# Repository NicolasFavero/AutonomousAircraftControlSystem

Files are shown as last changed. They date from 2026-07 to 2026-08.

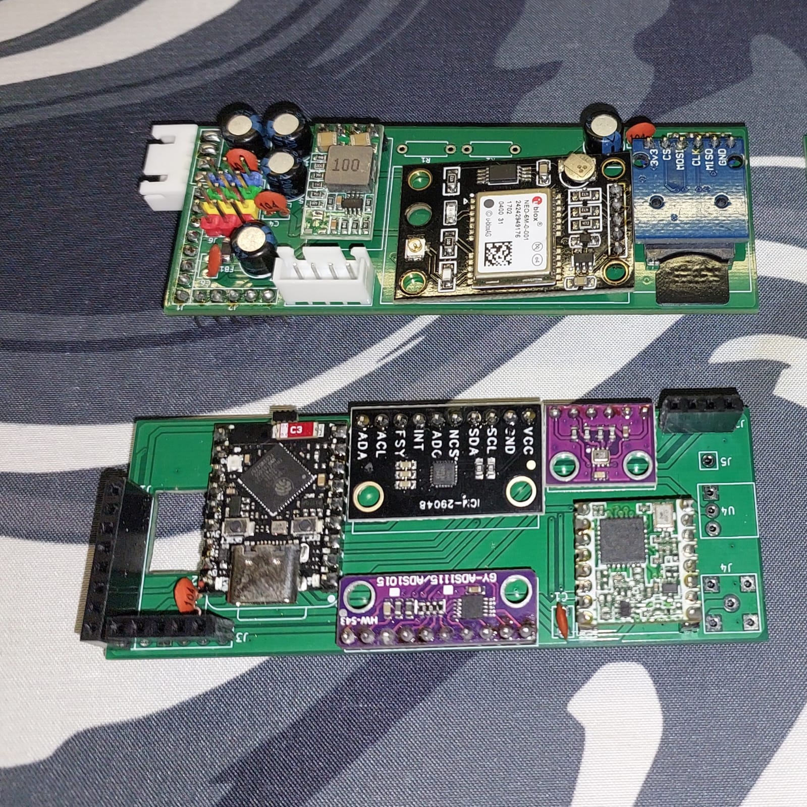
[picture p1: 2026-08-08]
media/pcb/image2.jpeg

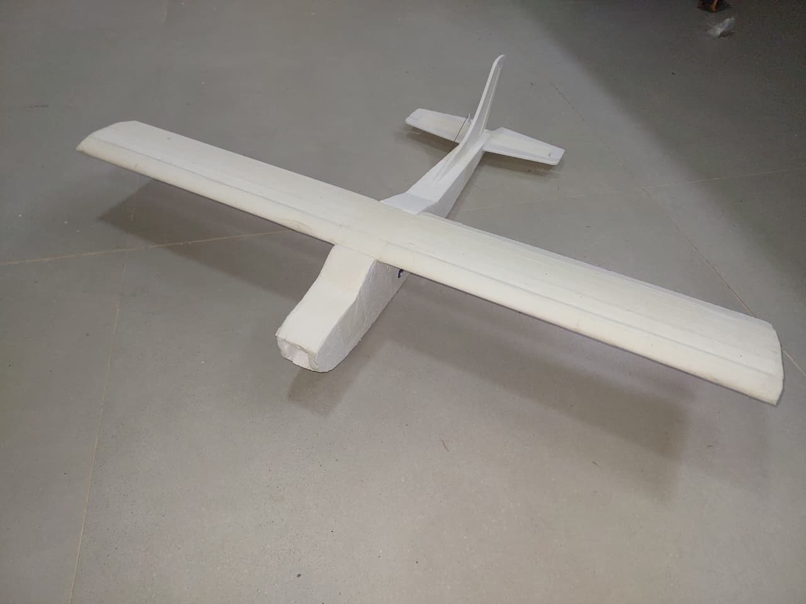
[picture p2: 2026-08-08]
media/aircraft/image3.jpeg

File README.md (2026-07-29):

# Sistema de Controle e Telemetria para Aeromodelo Autônomo

## Sobre o projeto

Este projeto consiste no desenvolvimento de um **sistema embarcado de controle, navegação e telemetria para uma asa autônoma / aeromodelo planador experimental**.

O sistema é baseado em um **ESP32-S3** e tem como finalidade realizar a aquisição de dados de voo, processamento de sensores, controle das superfícies móveis da aeronave e armazenamento das informações para análise posterior.

O projeto encontra-se em fase de **protótipo e desenvolvimento**, sendo utilizado para testes de hardware, sensores, algoritmos de controle e integração de sistemas embarcados.

---

## Objetivo

Desenvolver uma plataforma experimental para estudo e implementação de um sistema de controle autônomo para aeronaves de pequeno porte, integrando:

* Sensoriamento inercial e ambiental;
* Controle eletrônico das superfícies de comando;
* Registro de dados de voo;
* Desenvolvimento de firmware embarcado;
* Testes e validação de sistemas aplicados à aviação experimental.

---

## Funcionalidades

* Leitura de sensores inerciais:

  * Aceleração;
  * Velocidade angular;
  * Campo magnético;
* Medição de altitude e pressão atmosférica utilizando BMP280;
* Leitura de velocidade do ar através de tubo de Pitot;
* Controle das superfícies de comando:

  * Leme;
  * Aileron;
  * Profundor;
* Controle de servomotores;
* Registro de dados de voo em cartão SD;
* Estrutura preparada para futuras expansões, como telemetria e algoritmos de controle autônomo.

---

## Status do projeto

🚧 **Protótipo em desenvolvimento**

O firmware e o hardware ainda estão em fase experimental. Alterações na arquitetura, sensores utilizados e funcionalidades podem ocorrer durante o desenvolvimento.

---

## Tecnologias utilizadas

### Hardware

* ESP32-S3 SuperMini;
* ICM-20948 (IMU 9DOF);
* BMP280 (pressão e altitude);
* Tubo de Pitot;
* Servomotores;
* Cartão SD.

### Software

* C / C++;
* PlatformIO;
* Arduino Framework.

---

## Dependências

```ini
lib_deps =
	sparkfun/SparkFun 9DoF IMU Breakout - ICM 20948 - Arduino Library@^1.3.2
	adafruit/Adafruit ADS1X15@^2.6.2
	adafruit/Adafruit BMP280 Library@^3.0.0
	mikalhart/TinyGPSPlus@^1.1.0
	greiman/SdFat@^2.3.1
	jgromes/RadioLib@^7.7.1
```

---

## Ambiente de desenvolvimento

* IDE: PlatformIO;
* Framework: Arduino;
* Placa alvo: ESP32-S3 SuperMini.

---

## Estrutura do projeto

```
Firmware/
├── src/
├── include/
├── lib/
└── platformio.ini
```

---

## Aplicação

Projeto desenvolvido para fins educacionais e experimentais, integrando conhecimentos de **eletrônica, programação embarcada, sensores, controle e sistemas aeronáuticos** dentro de uma formação técnica em eletrônica.

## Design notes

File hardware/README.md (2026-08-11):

# Hardware

Esta pasta contém os arquivos de hardware do projeto, incluindo esquemáticos, layouts e demais arquivos relacionados às placas de circuito impresso (PCBs).

O sistema foi dividido em **duas PCBs empilháveis**, conectadas através de **headers macho e fêmea (2,54 mm)**. Essa arquitetura facilita a montagem, manutenção e futuras revisões do hardware, além de permitir uma melhor organização dos circuitos.

## PCB-Top

A **PCB-Top** concentra os circuitos de alimentação, armazenamento e navegação da aeronave, incluindo:

- Receptor GPS;
- Slot para cartão microSD;
- Conector da bateria;
- Conectores para servomotores;
- Conversor Buck (Step-Down);
- Capacitores de bulk para estabilização da alimentação;
- Distribuição das tensões de alimentação.

Também é nesta placa que ocorre a separação entre as linhas de alimentação de **3,3 V**, utilizando **ferrite beads** para isolar os diferentes domínios de alimentação, reduzindo a propagação de ruído entre os circuitos analógicos, digitais e de RF.

## PCB-Bottom

A **PCB-Bottom** concentra os circuitos responsáveis pelo processamento, sensoriamento e comunicação da aeronave, incluindo:

- ESP32-S3 SuperMini;
- IMU ICM-20948;
- BMP280;
- ADS1115;
- Módulo LoRa (RF96W ou módulos compatíveis da mesma família, como CC68);
- Conector para antena;
- Interface para tubo de Pitot.

A proximidade entre esses componentes reduz o comprimento das trilhas dos barramentos de comunicação e dos sinais de alta frequência, contribuindo para uma melhor integridade dos sinais.

## Interconexão

As duas placas são interligadas através de **headers macho e fêmea**, formando um conjunto compacto e removível.

Essa abordagem oferece diversas vantagens:

- Organização dos circuitos por função;
- Facilidade de montagem e manutenção;
- Possibilidade de substituir apenas uma das placas em futuras revisões;
- Redução da complexidade do roteamento;
- Melhor gerenciamento da distribuição de alimentação.

## Estrutura

```text
Hardware/
├── PCB-Top/
└── PCB-Bottom/
```

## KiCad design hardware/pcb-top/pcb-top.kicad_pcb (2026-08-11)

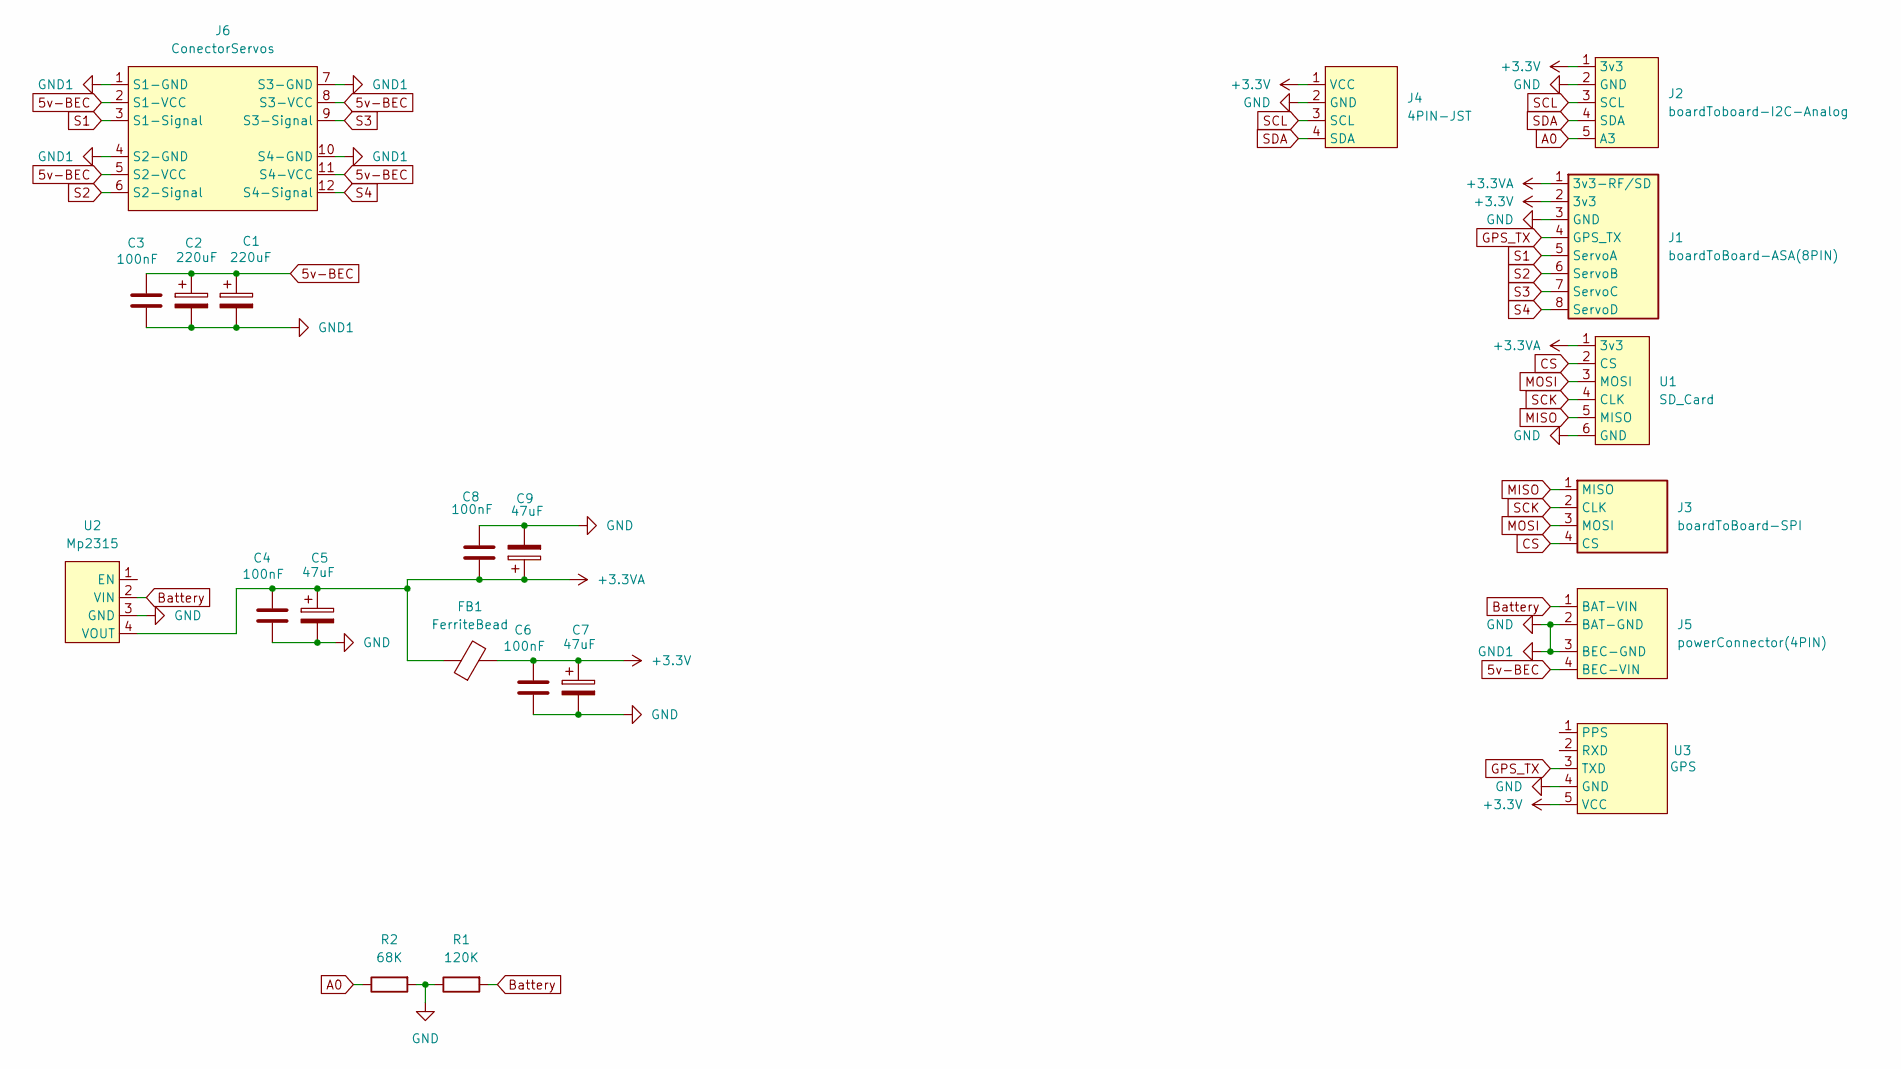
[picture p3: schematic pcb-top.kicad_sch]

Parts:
C1, C2: 220uF; CP_Radial_D6.3mm_P2.50mm
C3, C4, C6, C8: 100nF; C_Disc_D3.8mm_W2.6mm_P2.50mm
C5, C7, C9: 47uF; CP_Radial_D6.3mm_P2.50mm
FB1: FerriteBead; R_1206_3216Metric_Pad1.30x1.75mm_HandSolder
J1: boardToBoard-ASA(8PIN); PinSocket_1x08_P2.54mm_Vertical
J2: boardToboard-I2C-Analog; PinHeader_1x05_P2.54mm_Vertical
J3: boardToBoard-SPI; PinHeader_1x04_P2.54mm_Vertical
J4: 4PIN-JST; JST_XH_B4B-XH-A_1x04_P2.50mm_Vertical
J5: powerConnector(4PIN); ConnectorBaterry+BEC
J6: ConectorServos; 4Servos
R1: 120K; R_Axial_DIN0207_L6.3mm_D2.5mm_P7.62mm_Horizontal
R2: 68K; R_Axial_DIN0207_L6.3mm_D2.5mm_P7.62mm_Horizontal
U1: SD_Card
U2: Mp2315
U3: GPS

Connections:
5v-BEC: C1.1, C2.1, C3.1, J5.4 (BEC-VIN), J6.2 (S1-VCC), J6.5 (S2-VCC), J6.8 (S3-VCC), J6.11 (S4-VCC)
+3.3V: C6.1, C7.1, FB1.2, J1.2 (3v3), J2.1 (3v3), J4.1 (VCC), U3.5 (VCC)
+3.3VA: C4.1, C5.1, C8.1, C9.1, FB1.1, J1.1 (3v3-RF/SD), U1.1 (3v3), U2.4 (VOUT)
A0: J2.5 (A3), R2.1
Battery: J5.1 (BAT-VIN), R1.2, U2.2 (VIN)
CS: J3.4 (CS), U1.2 (CS)
GND: C1.2, C2.2, C3.2, C4.2, C5.2, C6.2, C7.2, C8.2, C9.2, J1.3 (GND), J2.2 (GND), J4.2 (GND), J5.2 (BAT-GND), J5.3 (BEC-GND), J6.1 (S1-GND), J6.4 (S2-GND), J6.7 (S3-GND), J6.10 (S4-GND), R1.1, R2.2, U1.6 (GND), U2.3 (GND), U3.4 (GND)
GPS_TX: J1.4 (GPS_TX), U3.3 (TXD)
MISO: J3.1 (MISO), U1.5 (MISO)
MOSI: J3.3 (MOSI), U1.3 (MOSI)
S1: J1.5 (ServoA), J6.3 (S1-Signal)
S2: J1.6 (ServoB), J6.6 (S2-Signal)
S3: J1.7 (ServoC), J6.9 (S3-Signal)
S4: J1.8 (ServoD), J6.12 (S4-Signal)
SCK: J3.2 (CLK), U1.4 (CLK)
SCL: J2.3 (SCL), J4.3 (SCL)
SDA: J2.4 (SDA), J4.4 (SDA)

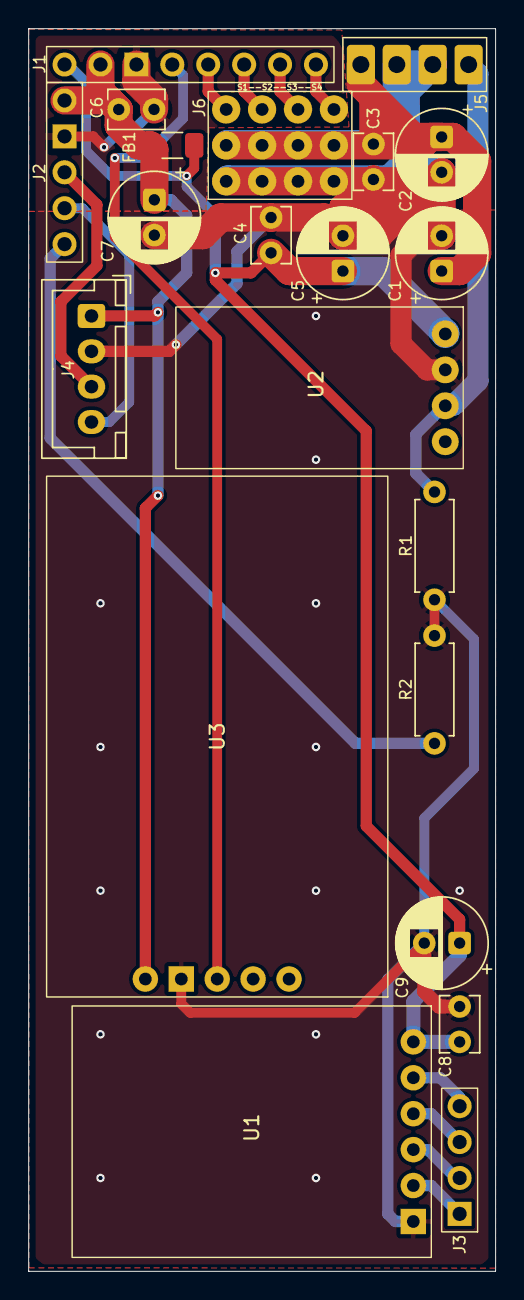
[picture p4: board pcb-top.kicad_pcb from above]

Board: 2 copper layers, 33.0 x 87.9 mm, 21 parts (0 on the bottom side), 17 nets.

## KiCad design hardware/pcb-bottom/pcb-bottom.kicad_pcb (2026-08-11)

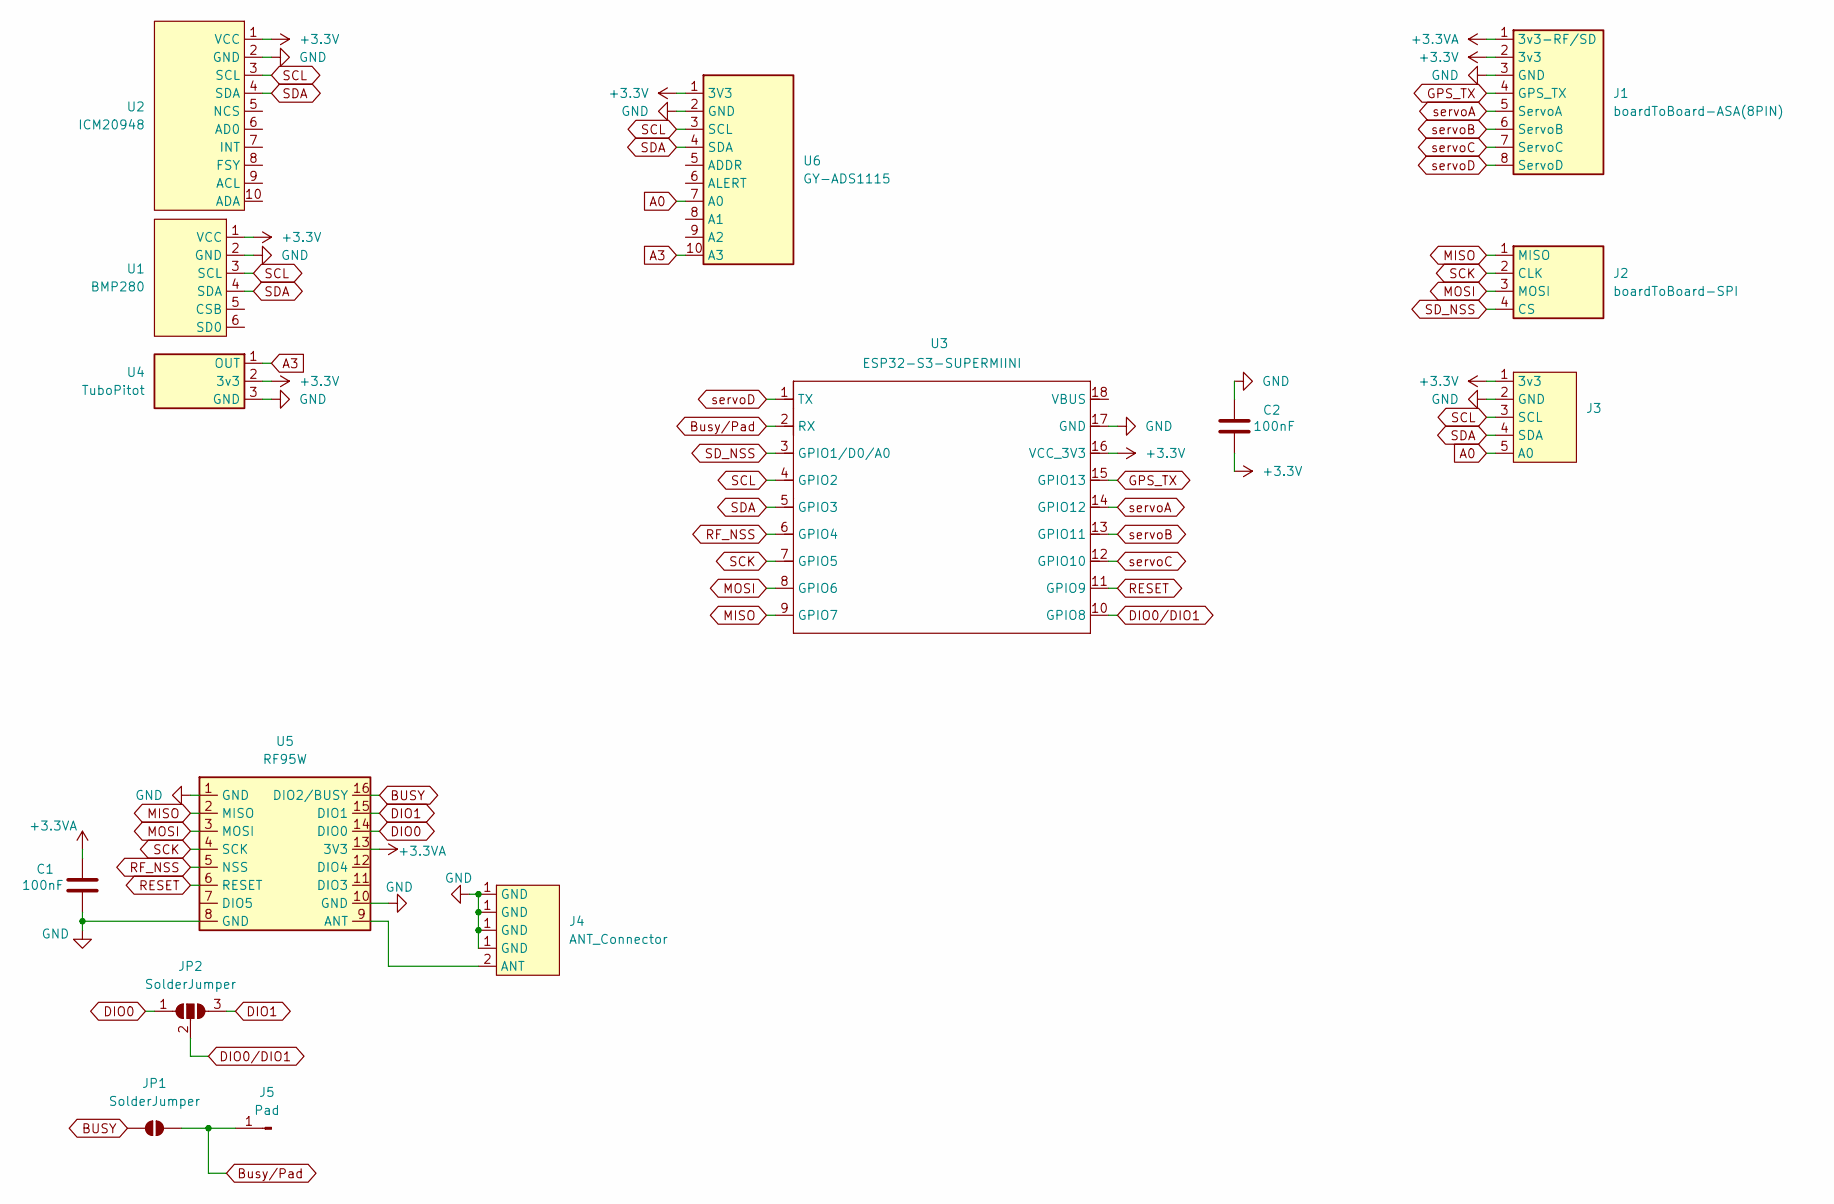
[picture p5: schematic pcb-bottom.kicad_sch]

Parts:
C1, C2: 100nF; C_Disc_D3.8mm_W2.6mm_P2.50mm
J1: boardToBoard-ASA(8PIN); PinHeader_1x08_P2.54mm_Vertical
J2: boardToBoard-SPI; PinHeader_1x04_P2.54mm_Vertical
J3: PinHeader_1x05_P2.54mm_Vertical
J4: ANT_Connector; conectorAntena2.54mm
J5: Pad; PinHeader_1x01_P2.54mm_Vertical
JP1: SolderJumper; SolderJumper-2_P1.3mm_Open_RoundedPad1.0x1.5mm
JP2: SolderJumper; SolderJumper-3_P1.3mm_Open_RoundedPad1.0x1.5mm
U1: BMP280
U2: ICM20948; ICM 20948
U3: ESP32-S3-SUPERMIINI; myEsp32-S3-Mini
U4: TuboPitot; tuboPitot
U5: RF95W; rf96w
U6: GY-ADS1115; ads1115

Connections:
+3.3V: C2.1, J1.2 (3v3), J3.1 (3v3), U1.1 (VCC), U2.1 (VCC), U3.16 (VCC_3V3), U4.2 (3v3), U6.1 (3V3)
+3.3VA: C1.2, J1.1 (3v3-RF/SD), U5.13 (3V3)
A0: J3.5 (A0), U6.7 (A0)
A3: U4.1 (OUT), U6.10 (A3)
BUSY: JP1.1 (A), U5.16 (DIO2/BUSY)
Busy/Pad: J5.1, JP1.2 (B), U3.2 (RX)
DIO0: JP2.1 (A), U5.14 (DIO0)
DIO0/DIO1: JP2.2 (C), U3.10 (GPIO8)
DIO1: JP2.3 (B), U5.15 (DIO1)
GND: C1.1, C2.2, J1.3 (GND), J3.2 (GND), J4.1 (GND), U1.2 (GND), U2.2 (GND), U3.17 (GND), U4.3 (GND), U5.1 (GND), U5.8 (GND), U5.10 (GND), U6.2 (GND)
GPS_TX: J1.4 (GPS_TX), U3.15 (GPIO13)
MISO: J2.1 (MISO), U3.9 (GPIO7), U5.2 (MISO)
MOSI: J2.3 (MOSI), U3.8 (GPIO6), U5.3 (MOSI)
unnamed: J4.2 (ANT), U5.9 (ANT)
RESET: U3.11 (GPIO9), U5.6 (RESET)
RF_NSS: U3.6 (GPIO4), U5.5 (NSS)
SCK: J2.2 (CLK), U3.7 (GPIO5), U5.4 (SCK)
SCL: J3.3 (SCL), U1.3 (SCL), U2.3 (SCL), U3.4 (GPIO2), U6.3 (SCL)
SDA: J3.4 (SDA), U1.4 (SDA), U2.4 (SDA), U3.5 (GPIO3), U6.4 (SDA)
SD_NSS: J2.4 (CS), U3.3 (GPIO1/D0/A0)
servoA: J1.5 (ServoA), U3.14 (GPIO12)
servoB: J1.6 (ServoB), U3.13 (GPIO11)
servoC: J1.7 (ServoC), U3.12 (GPIO10)
servoD: J1.8 (ServoD), U3.1 (TX)

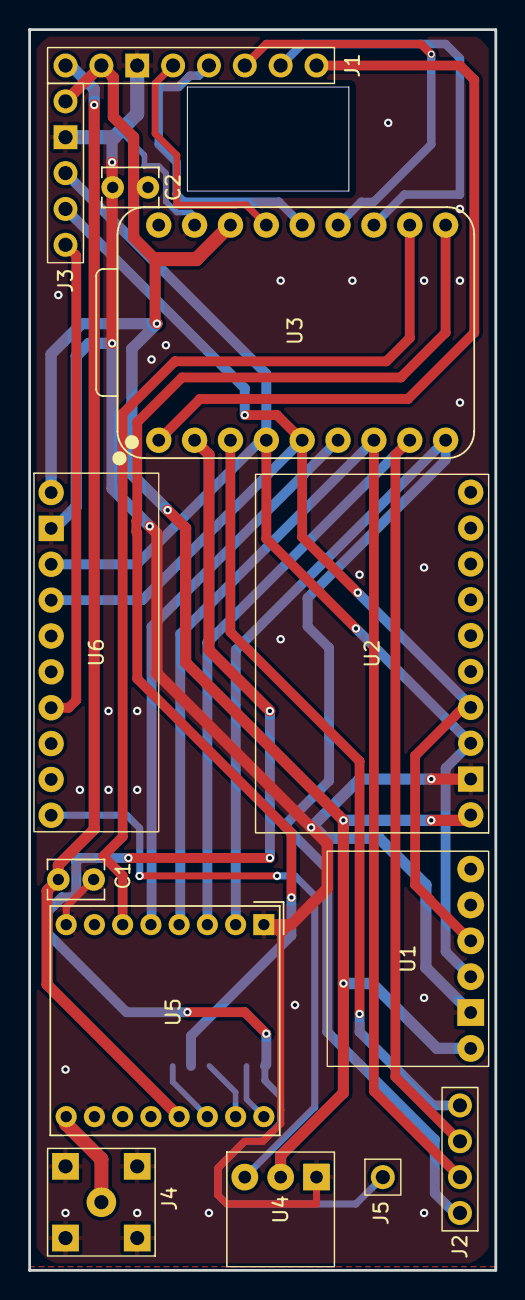
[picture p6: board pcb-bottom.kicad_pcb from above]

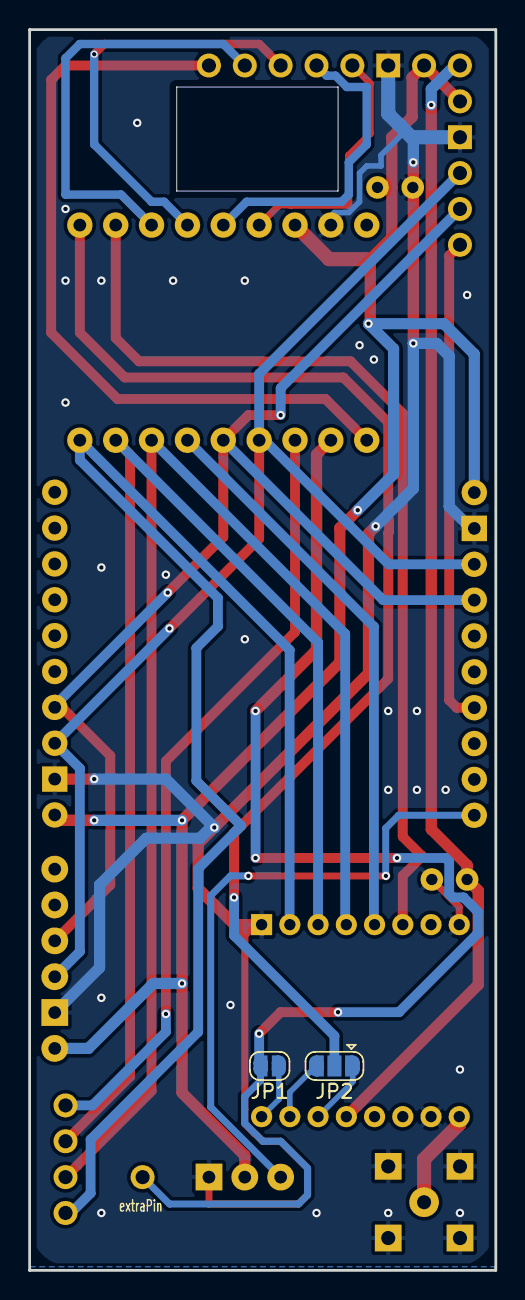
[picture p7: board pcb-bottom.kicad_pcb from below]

Board: 2 copper layers, 33.0 x 87.9 mm, 15 parts (2 on the bottom side), 24 nets.

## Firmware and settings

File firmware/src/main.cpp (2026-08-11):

// Arduino
#include "Arduino.h"

// Config
#include "Pins.h"
#include "ServomotorConfig.h"
#include "DataTypes.h"
#include "CurrentConfig.h"

// Drivers
#include "IMU.h"
#include "GPS.h"
#include "ApplyGpsConfig.h"
#include "gpsSettings.h"
#include "BMP280.h"
#include "ADS1X15.h"
#include "Pitot.h"

// Communication
#include "RF96W.h"
#include "WiFiAP.h"

// Storage
#include "SdLogger.h"
#include "PreferencesManager.h"

// Control
#include "PID.h"
#include "Servo.h"

// Telemetry
#include "Telemetry.h" //ALTEREI PRA DEBUG     float pitch = imuValid ? attitude.pitch : 0.0f; LEMBRAR DE VOLTAR ATRAS DEPOIS!!!!!!!!!!!!!!!

// Debug
#include "Led.h"
//=======================================================================================================================================================
//OTHERS
unsigned long lastTelemetryMillis = 0;
unsigned long countdownStartMillis = 0;
constexpr unsigned long COUNTDOWN_DURATION_MS = 10000; // mesmo valor do COUNTDOWN_DURATION_S no script.js

// Timer PROPRIO do registro no SD (ver handleOutputs()) -- antes
// reusava a mesma lastTelemetryMillis do envio LoRa, o que fazia o
// registro no SD "resetar o relogio" que o LoRa checava logo em
// seguida, e o LoRa quase nunca dava tempo de vencer o periodo
// configurado. Agora sao independentes: SD grava a cada
// SD_LOG_INTERVAL_MS, LoRa manda a cada systemConfig.telemetryPeriodMs,
// sem um atrapalhar o outro.
unsigned long lastSdMillis = 0;
constexpr unsigned long SD_LOG_INTERVAL_MS = 10;
volatile bool newOffsetsAvailable = false;
volatile bool newPidAvailable = false;

bool wifiEnabled = false;
bool wifiTemporary = false;

unsigned long wifiStartMillis = 0;
//==================================================================STRUCTS===============================================================================
ImuOffsets currentOffsets;
PidConfig currentPidConfig;
SystemConfig systemConfig;
SystemStatus systemStatus;
GpsConfigStatus gpsConfigStatus;
//========================================================================================================================================================
//==================================================================CLASSES==============================================================================
// Drivers
IMU imu;
ADS ads;
Pitot pitot(ads);
BMP280 bmp;

// GPS: ApplyGpsConfig (aplicada uma vez em beginGps(), setup()) e GPS
// (parser continuo, TinyGPSPlus) compartilham a MESMA UART -- nenhuma
// das duas possui/cria a HardwareSerial, so' recebem por referencia.
HardwareSerial gpsSerial(1);
GPS gps(gpsSerial);

// Communication
RF96W lora(Pins::LORA_CS, Pins::LORA_DIO0, Pins::LORA_RESET, systemConfig.lora);
WifiAP wifi;

// Storage
SdLogger sd(Pins::SD_CS);
PreferencesManager nvs;

// Control
PID pid;

// Actuators
//
// minAngle/maxAngle (ultimos 2 args) NAO sao mais o default generico
// 0-180 do construtor -- sao o fim de curso mecanico real de cada servo
// (ServoConfig::SafeRange), pra' write() (lib/Servo) recusar qualquer
// angulo fora disso, venha de onde vier a chamada (PID ou o trim
// direto em main.cpp). Antes disso um trim grande demais no "Aplicar e
// Travar Servos" conseguia mandar o servo direto pro batente fisico
// sem nenhum clamp no meio do caminho.
Servo elevator    (Pins::ELEVATOR,      ServoConfig::Channel::ELEVATOR,      ServoConfig::FREQUENCY, ServoConfig::RESOLUTION, 500, 2500, ServoConfig::SafeRange::ELEVATOR_MIN,      ServoConfig::SafeRange::ELEVATOR_MAX);
Servo leftAlieron (Pins::LEFT_AILERON,  ServoConfig::Channel::LEFT_AILERON,  ServoConfig::FREQUENCY, ServoConfig::RESOLUTION, 500, 2500, ServoConfig::SafeRange::LEFT_AILERON_MIN,  ServoConfig::SafeRange::LEFT_AILERON_MAX);
Servo rightAlieron(Pins::RIGHT_AILERON, ServoConfig::Channel::RIGHT_AILERON, ServoConfig::FREQUENCY, ServoConfig::RESOLUTION, 500, 2500, ServoConfig::SafeRange::RIGHT_AILERON_MIN, ServoConfig::SafeRange::RIGHT_AILERON_MAX);
//Servo rudder    (Pins::RUDDER,        ServoConfig::Channel::RUDDER,        ServoConfig::FREQUENCY, ServoConfig::RESOLUTION); 

// Telemetry
Telemetry telemetry;

//Visual Debug
Led led;

//========================================================================================================================================================
//==============================================================FREEERTOS QUEUES===============================================================================
QueueHandle_t attitudeQueue;
QueueHandle_t navigationQueue;
portMUX_TYPE offsetMux = portMUX_INITIALIZER_UNLOCKED;
portMUX_TYPE pidMux = portMUX_INITIALIZER_UNLOCKED;
//========================================================================================================================================================
//=================================================================PROTOTYPES=============================================================================
// TASKS
void taskControl(void *pv);
void taskData(void *pv);

// TASK CONTROL HELPERS
bool readAttitudeData(AttitudeData& attitude);
void syncPidNeutralAngles();

// TASK DATA HELPERS
void sendNavigationData(NavigationData& navigationData);
void handleWifiTimeout();
void handleOutputs(FlightMode mode);
void handleWifi(const AttitudeData& attitude, const NavigationData& navigationData);
void updateGpsStatus();
void setupWifi();
bool beginGps();
TelemetryData buildTelemetryData(AttitudeData& attitude);
// GENERAL HELPERS
bool isLowPowerModeEnabled();

// Recalcula o neutro (BaseNeutral + trim) dos 3 servos a partir de
// currentPidConfig -- inclui o sinal do trim invertido quando
// invertFlaperonTrim/invertElevatorTrim esta' ligado (ver comentario
// em PidConfig, DataTypes.h: existe pq o teclado numerico do celular
// nao tem "-"). Chamada tanto no boot quanto sempre que a config muda
// (bloco "newPidAvailable" em taskControl()), pra nao duplicar essa
// conta nos dois lugares.
void syncPidNeutralAngles(){
  float flapTrim = currentPidConfig.invertFlaperonTrim
      ? -currentPidConfig.flaperonTrim
      : currentPidConfig.flaperonTrim;

  float elevTrim = currentPidConfig.invertElevatorTrim
      ? -currentPidConfig.elevatorTrim
      : currentPidConfig.elevatorTrim;

  // Clampado no fim de curso real (ServoConfig::SafeRange) -- sem isso
  // um trim grande demais produzia um neutralAngle fora do range
  // seguro, e o "Aplicar e Travar Servos" (setAngle = neutralAngle,
  // logo abaixo) escrevia esse valor DIRETO no servo sem passar por
  // nenhum constrain (diferente do caminho do PID, que sempre clampou
  // via PID::applyServoOutput). O objeto Servo (lib/Servo) tambem
  // clampa no mesmo range como ultima linha de defesa, mas isso aqui
  // evita que a UI mostre um "neutro" mentiroso, fora do que o servo
  // fisicamente consegue atingir.
  pid.elevator.neutralAngle = constrain(
      ServoConfig::BaseNeutral::ELEVATOR + elevTrim,
      ServoConfig::SafeRange::ELEVATOR_MIN,
      ServoConfig::SafeRange::ELEVATOR_MAX
  );

  pid.leftAileron.neutralAngle = constrain(
      ServoConfig::BaseNeutral::LEFT_AILERON + flapTrim,
      ServoConfig::SafeRange::LEFT_AILERON_MIN,
      ServoConfig::SafeRange::LEFT_AILERON_MAX
  );

  pid.rightAileron.neutralAngle = constrain(
      ServoConfig::BaseNeutral::RIGHT_AILERON - flapTrim,
      ServoConfig::SafeRange::RIGHT_AILERON_MIN,
      ServoConfig::SafeRange::RIGHT_AILERON_MAX
  );
}

//=========================================================================================================================================================
//===================================================================SETUP=================================================================================
void setup(){
  Serial.begin(115200);
  Serial.println("Beginning...");
  Wire.begin(Pins::SDA, Pins::SCL);
  Wire.setClock(400000); 

  SPI.begin(Pins::SCK, Pins::MISO, Pins::MOSI);

  led.white();
  //led.white();

  nvs.loadSystem(systemConfig);
  nvs.loadOffsets(currentOffsets);
  nvs.loadPid(currentPidConfig);

  pitot.setZeroVoltage(currentOffsets.pitotZeroVoltage);

  // Sem isso, o offset salvo nas Preferences so era realmente
  // aplicado no calculo do angulo (localOffsets, dentro da task de
  // controle) depois que o usuario salvasse um offset pela web --
  // ate la, localOffsets ficava zerado mesmo com currentOffsets/
  // /api/status ja reportando o valor salvo do boot anterior. Isso
  // fazia a primeira tara depois de ligar somar o offset antigo (que
  // NAO estava de fato sendo subtraido da leitura) com o novo valor
  // calculado, dando um offset errado logo na primeira vez -- so
  // acertava no segundo, quando o evento OFFSET_CHANGED sincronizava
  // localOffsets pela primeira vez. Marcando newOffsetsAvailable aqui,
  // a task de controle sincroniza localOffsets = currentOffsets logo
  // na primeira iteracao do loop, antes de qualquer leitura ser usada.
  newOffsetsAvailable = true;

  pid.pitch.kp = currentPidConfig.pitch.kp;
  pid.pitch.ki = currentPidConfig.pitch.ki;
  pid.pitch.kd = currentPidConfig.pitch.kd;
  pid.pitch.integralLimit = currentPidConfig.pitch.integralLimit;

  pid.roll.kp = currentPidConfig.roll.kp;
  pid.roll.ki = currentPidConfig.roll.ki;
  pid.roll.kd = currentPidConfig.roll.kd;
  pid.roll.integralLimit = currentPidConfig.roll.integralLimit;

  pid.yaw.kp = currentPidConfig.yaw.kp;
  pid.yaw.ki = currentPidConfig.yaw.ki;
  pid.yaw.kd = currentPidConfig.yaw.kd;
  pid.yaw.integralLimit = currentPidConfig.yaw.integralLimit;

  // Neutro fisico (ServoConfig::BaseNeutral) + trim configuravel
  // (currentPidConfig, carregado das Preferences acima) -- sem isso,
  // leftAileron/rightAileron ficariam nos 90.0f default de
  // PID::ServoParamters (errado: a base fisica real e' 85/103) ate a
  // primeira mudanca de PID pela pagina web. setAngle tambem e' fixado
  // aqui pro servo ja nascer na posicao certa (fora do modo FLIGHT,
  // computePID() nao roda pra atualizar isso sozinho).
  syncPidNeutralAngles();

  pid.elevator.setAngle    = pid.elevator.neutralAngle;
  pid.leftAileron.setAngle = pid.leftAileron.neutralAngle;
  pid.rightAileron.setAngle = pid.rightAileron.neutralAngle;

  while(!imu.begin()){led.red();}
  Serial.println("[BOOT] IMU ok");

  while(!bmp.begin()){led.red();}
  Serial.println("[BOOT] BMP280 ok");

  Serial.println("[BOOT] Iniciando GPS (beginGps())...");
  gpsSerial.begin(9600, SERIAL_8N1, Pins::GPS_TX, Pins::GPS_RX);
  delay(10);
  while(!beginGps()){led.red();}
  Serial.println("[BOOT] GPS ok");

  // TESTE SEM ADS1115: pulando ads.begin() (sem isso, o while
  // travaria pra sempre esperando um chip que nao esta na placa).
  // while(!ads.begin()){led.red();}
  // Serial.println("[BOOT] ADS1115 ok");

  while(!lora.begin()){led.red();}
  Serial.println("[BOOT] LoRa ok");

  while(!elevator.begin()){led.red();}
  Serial.println("[BOOT] Servo elevator ok");

  while(!leftAlieron.begin()){led.red();}
  Serial.println("[BOOT] Servo aileron esquerdo ok");

  while(!rightAlieron.begin()){led.red();}
  Serial.println("[BOOT] Servo aileron direito ok");

  while(!sd.begin()) {Serial.println("SD FAIL"); led.red();}
  Serial.println("[BOOT] SD ok");

  // Buffer em RAM/PSRAM pros logs de voo -- ver comentarios em
  // SdLogger::beginBuffer()/bufferLine(). Se falhar (placa sem PSRAM
  // ou sem RAM livre suficiente), o firmware continua funcionando,
  // so volta a escrever direto no SD a cada leitura como antes.
  //
  // 512KB (era o default de 64KB) -- o log no SD agora grava a cada
  // SD_LOG_INTERVAL_MS (10ms, 10x mais rapido que antes), entao o
  // buffer tambem precisa ser maior pra continuar enchendo (e forcando
  // o flush real, bloqueante, no cartao) com a mesma frequencia de
  // antes em vez de 10x mais frequente. Cabe tranquilo na PSRAM do
  // ESP32-S3.
  sd.beginBuffer(512 * 1024);

  attitudeQueue = xQueueCreate(1, sizeof(AttitudeData));
  navigationQueue = xQueueCreate(1, sizeof(NavigationData));

  if(attitudeQueue == NULL || navigationQueue == NULL){
    while(true){
      led.red();
      delay(500);
    }
  }
  setupWifi();

  lastTelemetryMillis = millis();

  led.green();
  
  xTaskCreatePinnedToCore(
    taskControl,
    "Control",
    10000,
    NULL,
    2,
    NULL,
    0
  );
  xTaskCreatePinnedToCore(
    taskData,
    "Data",
    10000,
    NULL,
    1,
    NULL,
    1
  );
}
//==========================================================================================================================================================
//================================================================KILLING TASK==============================================================================
void loop(){vTaskDelete(NULL);}
//==========================================================================================================================================================
//=================================================================TASK AT CORE 0===========================================================================
void taskControl(void *pv){

  TickType_t lastWake = xTaskGetTickCount();
  const TickType_t period = pdMS_TO_TICKS(5); //200HZ

  while(true){
    bool useNewValues = true;

    static AttitudeData attitudeData;
    static NavigationData nav; 
    static ImuOffsets localOffsets; 
  //===================TO  ATTITUDE==============
    if(systemConfig.flightMode == FlightMode::CONFIG && newOffsetsAvailable){
      portENTER_CRITICAL(&offsetMux);

      localOffsets = currentOffsets;

      newOffsetsAvailable = false;

      portEXIT_CRITICAL(&offsetMux);
    }

    // Fora do CONFIG, so' processa mudanca de PID/trim se liveTuningEnabled
    // estiver ligado (marcado na hora de "Iniciar Voo", ver
    // handleStartFlight() em WifiAP.cpp) E o modo for FLIGHT de verdade
    // -- nunca em COUNTDOWN/LANDED, que continuam travados como sempre
    // (handlePid() ja rejeita o POST nesses casos antes de chegar aqui).
    bool pidLiveTuningNow =
        systemConfig.liveTuningEnabled &&
        systemConfig.flightMode == FlightMode::FLIGHT;

    if(newPidAvailable && (systemConfig.flightMode == FlightMode::CONFIG || pidLiveTuningNow)){
      portENTER_CRITICAL(&pidMux);

      pid.pitch.kp = currentPidConfig.pitch.kp;
      pid.pitch.ki = currentPidConfig.pitch.ki;
      pid.pitch.kd = currentPidConfig.pitch.kd;
      pid.pitch.integralLimit = currentPidConfig.pitch.integralLimit;

      pid.roll.kp = currentPidConfig.roll.kp;
      pid.roll.ki = currentPidConfig.roll.ki;
      pid.roll.kd = currentPidConfig.roll.kd;
      pid.roll.integralLimit = currentPidConfig.roll.integralLimit;

      pid.yaw.kp = currentPidConfig.yaw.kp;
      pid.yaw.ki = currentPidConfig.yaw.ki;
      pid.yaw.kd = currentPidConfig.yaw.kd;
      pid.yaw.integralLimit = currentPidConfig.yaw.integralLimit;

      syncPidNeutralAngles();

      // So' forca a posicao final (setAngle = neutralAngle) em CONFIG --
      // e' o que faz o servo se mover na hora que o trim muda, "forcar e
      // travar" na pagina Servos/PID (fora do FLIGHT, computePID() nao
      // roda pra atualizar isso sozinho). Durante o FLIGHT (so' chega
      // aqui com pidLiveTuningNow), computePID() ja' roda todo ciclo e
      // aplica o neutro/ganho novo sozinho -- forcar setAngle aqui
      // tambem brigaria com a correcao em tempo real dele.
      if(systemConfig.flightMode == FlightMode::CONFIG){
        pid.elevator.setAngle     = pid.elevator.neutralAngle;
        pid.leftAileron.setAngle  = pid.leftAileron.neutralAngle;
        pid.rightAileron.setAngle = pid.rightAileron.neutralAngle;
      }

      newPidAvailable = false;

      portEXIT_CRITICAL(&pidMux);
    }

    imu.update();

    if(systemConfig.flightMode == FlightMode::FLIGHT){
      pid.setAngles(attitudeData, nav, useNewValues);
    }


    elevator.write(pid.elevator.setAngle);
    leftAlieron.write(pid.leftAileron.setAngle);
    rightAlieron.write(pid.rightAileron.setAngle);

  //===================TO  ATTITUDE==============
  //=====================FOR SEND================
    attitudeData.pitch = imu.getPitch() - localOffsets.pitch;
    attitudeData.roll = imu.getRoll() - localOffsets.roll;
    attitudeData.yaw = imu.getYaw() - localOffsets.yaw;

    // Mesmo valor que acabou de ir pro elevator.write()/leftAlieron.write()/
    // rightAlieron.write() acima -- registrado aqui, e nao lido de volta do
    // servo, porque servo (PWM) nao tem telemetria de posicao real.
    attitudeData.servoElevator = pid.elevator.setAngle;
    attitudeData.servoLeftAileron = pid.leftAileron.setAngle;
    attitudeData.servoRightAileron = pid.rightAileron.setAngle;

    attitudeData.accX = imu.getAccX();
    attitudeData.accY = imu.getAccY();
    attitudeData.accZ = imu.getAccZ();

    attitudeData.gyroX = imu.getGyroX();
    attitudeData.gyroY = imu.getGyroY();
    attitudeData.gyroZ = imu.getGyroZ();

    attitudeData.magX= imu.getMagX();
    attitudeData.magY = imu.getMagY();
    attitudeData.magZ = imu.getMagZ();

    attitudeData.isImuOk = imu.isHealthy();

    xQueueOverwrite(attitudeQueue, &attitudeData);
  //=====================FOR SEND================
  //====================TO  RECEIVE==============
    if(xQueueReceive(navigationQueue,&nav,0)){useNewValues = true;}
  //====================TO  RECEIVE==============
  
    vTaskDelayUntil(&lastWake,period);
  }
}
//==========================================================================================================================================================
//=================================================================TASK AT CORE 1===========================================================================
void taskData(void *pv){

  TickType_t lastWake = xTaskGetTickCount();
  // Era 100ms/10Hz -- baixado pra 10ms/100Hz pra' o log no SD
  // (SD_LOG_INTERVAL_MS, dentro de handleOutputs()) conseguir gravar de
  // verdade a cada 10ms, ja' que ele so' roda quando esse loop roda.
  // O resto do trabalho aqui dentro (GPS/BMP/WiFi) ou se beneficia de
  // rodar mais vezes (GPS.update() drena a UART com mais frequencia,
  // handleWifi() atende requisicoes HTTP mais rapido) ou e' barato o
  // suficiente pra nao importar (leitura do BMP280, montagem de JSON) --
  // exceto o envio LoRa, que continua no proprio periodo configurado
  // (systemConfig.telemetryPeriodMs), sem depender do periodo do loop.
  const TickType_t period = pdMS_TO_TICKS(10); //100HZ
  static bool isImuValid = false;

  while(true){

    static NavigationData navigationData;
    static AttitudeData attitude;

    readAttitudeData(attitude);

    systemStatus.bmpOk = bmp.update();
    systemStatus.imuOk = attitude.isImuOk;

    // pitot.update(); // TESTE SEM ADS1115

    if(gps.update()){led.green(); /*Serial.println("GPS Atualizado");*/}
    else{led.blue();}

    if(systemConfig.flightMode == FlightMode::COUNTDOWN){

        unsigned long elapsed = millis() - countdownStartMillis;

        if(elapsed >= COUNTDOWN_DURATION_MS){
            systemConfig.flightMode = FlightMode::FLIGHT;
            wifi.setFlightMode(systemConfig.flightMode);
            wifi.setCountdownRemaining(0);
        }
        else{
            wifi.setCountdownRemaining(COUNTDOWN_DURATION_MS - elapsed);
        }
    }
    else{
        wifi.setCountdownRemaining(0);
    }

    telemetry.update(buildTelemetryData(attitude));

    sendNavigationData(navigationData);

    handleOutputs(systemConfig.flightMode);//Sends LoRa Packets and registers logs in SD_Card, it update systemStatus.loraOk

    // Modo de voo "WiFi": o unico modo por enquanto mantem o WiFi
    // ativo mesmo durante o FLIGHT, entao o AP continua respondendo
    // (status, Finalizar Voo, telemetria) em vez de ficar mudo ate
    // o pouso. Logs no SD e envio LoRa continuam de qualquer forma,
    // isso e controlado em handleOutputs().
    if(wifiEnabled){
      handleWifi(attitude, navigationData);
      updateGpsStatus();
    }
    else{
      handleWifiTimeout();
    }

    vTaskDelayUntil(&lastWake, period);
  }
}
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

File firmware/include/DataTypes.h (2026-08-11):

#pragma once
#include <Arduino.h>

struct AttitudeData{
    float pitch = 0.0f;
    float roll = 0.0f;
    float yaw = 0.0f;

    // Posicao (em graus) efetivamente mandada pro servo naquele ciclo --
    // ou seja, angle.elevator/leftAileron/rightAileron ja depois do PID +
    // slew-rate + limite de hardware (ver PID::computePID). Fica perto do
    // pitch/roll/yaw de proposito, pra facilitar comparar o angulo lido
    // vs o angulo comandado no mesmo instante.
    float servoElevator = 90.0f;
    float servoLeftAileron = 90.0f;
    float servoRightAileron = 90.0f;

    float accX = 0.0f;
    float accY = 0.0f;
    float accZ = 0.0f;

    float gyroX = 0.0f;
    float gyroY = 0.0f;
    float gyroZ = 0.0f;

    float magX = 0.0f;
    float magY = 0.0f;
    float magZ = 0.0f;

    bool isImuOk = false;
};

struct NavigationData{
    double latitude = 0.0f;
    double longitude = 0.0f;

    float gpsAltitude = 0.0f;
    float course = 0.0f;

    uint8_t satellites = 0;

    float baroAltitude = 0.0f;
    float temperature = 0.0f;
    float battery = 0.0f;

    float airspeed = 0.0f;        // m/s, com sinal (Pitot -- ver lib/Pitot)
    float pitotRawVoltage = 0.0f; // tensao ADS crua no canal do pitot (SEM zero/filtro) -- so pra diagnostico/tara na pagina web
};


/*==========================================================
                    IMU Offsets
==========================================================*/

struct ImuOffsets
{
    float pitch = 0.0f;
    float roll = 0.0f;
    float yaw = 0.0f;

    // Nao e' da IMU, e' o zero do Pitot (MPXV7002DP) -- mora aqui
    // mesmo assim pra reusar o mesmo fluxo de tara/salvar/Preferences
    // que pitch/roll/yaw ja tem (mesmo padrao de SystemConfig.lora
    // ja fazer algo parecido). 1.8385V e' o zero de fabrica (sem
    // media estatica no boot -- ver comentario em Pitot::update()).
    float pitotZeroVoltage = 1.8385f;
};

/*==========================================================
                    PID Gains
==========================================================*/

struct PidGains
{
    float kp = 0.0f;
    float ki = 0.0f;
    float kd = 0.0f;

    // Teto do anti-windup (PID::PID_variables::integral fica preso em
    // [-integralLimit, +integralLimit]). Default 0.0f == integral sempre
    // travado em 0 (Ki sem efeito nenhum) ate' ser configurado pela
    // pagina PID -- mesmo comportamento "inerte" de antes desse campo
    // existir, so' que agora configuravel em vez de permanentemente
    // zerado (ver PID::updatePidVariables em lib/PID/PID.cpp).
    float integralLimit = 0.0f;
};

struct PidConfig
{
    PidGains pitch;
    PidGains roll;
    PidGains yaw; // Ainda nao usado no controle, mas ja fica pronto.

    // Trim simetrico por cima do neutro FISICO de cada servo (ver
    // ServoConfig::BaseNeutral) -- e' o que a pagina Servos/PID
    // realmente edita, nunca os graus base direto. flaperonTrim>0
    // soma no neutro do aileron esquerdo e SUBTRAI do direito (ver
    // comentario em main.cpp sobre qual direcao fisica isso vira --
    // confirme no teste com os servos de verdade, e' so trocar o sinal
    // aqui se estiver invertido).
    float flaperonTrim = 0.0f;
    float elevatorTrim = 0.0f;

    // Inverte o sinal do trim antes de aplicar (LEFT_AILERON + trim /
    // RIGHT_AILERON - trim, ver main.cpp::syncPidNeutralAngles()).
    // Existe porque o input numerico do navegador no celular nao tem
    // tecla de "-" -- sem isso, corrigir a direcao do trim exigiria
    // digitar um valor negativo, o que nao da' pra fazer no celular.
    bool invertFlaperonTrim = false;
    bool invertElevatorTrim = false;
};

struct LoraConfig
{
    float frequency = 915.0f;

    float bandwidth = 125.0f;

    uint8_t spreadingFactor = 10;

    uint8_t codingRate = 5;

    uint8_t power = 20;

    uint16_t preambleLength = 8;

    uint8_t syncWord = 0x12;
};

enum class FlightMode : uint8_t
{
    CONFIG,
    COUNTDOWN,
    FLIGHT,
    LANDED
};

/*==========================================================
                    GPS Status
==========================================================*/

enum class GpsStatus : uint8_t
{
    NO_COMMUNICATION = 0,   // Vermelho
    NO_FIX           = 1,   // Laranja
    POOR_FIX         = 2,   // Amarelo
    GOOD_FIX         = 3    // Verde
};

// Resultado da aplicacao da config UBX no boot (ApplyGpsConfig, dentro
// de GPS::begin()) -- diferente de GpsStatus acima, que e' o fix ao
// vivo (muda o tempo todo). Isso aqui e' fixo depois do boot, so serve
// pra diagnostico: a config realmente foi aplicada no modulo, ou o GPS
// nem respondeu?
struct GpsConfigStatus
{
    bool ok = false; // true so se TODOS os comandos de gpsSettings.h foram confirmados por ACK

    uint32_t detectedBaud = 0; // baud em que o GPS respondeu ANTES de aplicar a config (0 = nenhum candidato respondeu)
    uint32_t finalBaud = 0;    // baud em que a UART fica depois de aplicar (pode ter mudado por um comando de troca de baudrate)

    uint8_t confirmedCount = 0;
    uint8_t totalCount = 0;

    // Leitura de volta (CFG-PRT/RATE/NAV5/GNSS) -- ja vem como um
    // objeto JSON valido (ex.: {"baud":115200,"rateMs":140,...}), pra
    // poder ser embutido direto (sem escapar aspas) dentro do JSON que
    // o WifiAP manda pro navegador.
    char configJson[320] = "{}";
};

enum class SystemEvent : uint8_t{
    NONE,

    OFFSET_CHANGED,
    PID_CHANGED,
    SYSTEM_CHANGED,
    LORA_CHANGED,

    CHECK_SD,
    CHECK_LORA,
    CHECK_GPS,

    START_FLIGHT,
    END_FLIGHT,
    DEACTIVATE_FLIGHT,
    RESET_FLIGHT,

    DELETE_ALL_LOGS,
    DELETE_LOG,
    RENAME_LOG,

    TELEMETRY_REQUEST,

    RESTART
};
struct SystemConfig
{
    float batteryLimit = 7.5f;

    uint16_t telemetryPeriodMs = 1000;

    uint16_t lowBatteryTelemetryPeriodMs = 10000;

    uint16_t estimatedFlightTimeMin = 30;

    bool wifiEnabled = true;

    bool preFlightTelemetryEnabled = false;

    FlightMode flightMode = FlightMode::CONFIG;

    // Decidido na hora de "Iniciar Voo" (checkbox na pagina Voo, ver
    // handleStartFlight() em WifiAP.cpp) -- default desligado (a
    // configuracao so' pode ser editada em CONFIG, como sempre foi).
    // Ligado, libera PID/trim pra edicao tambem durante o FLIGHT (ver
    // handlePid() e o bloco "newPidAvailable" em taskControl()).
    // Proposital NAO ter chave nas Preferences: cada voo exige marcar
    // de novo, nunca herda do voo anterior.
    bool liveTuningEnabled = false;

    LoraConfig lora;
};

struct SystemStatus
{
    bool imuOk = false;

    GpsStatus gpsStatus = GpsStatus::NO_COMMUNICATION;

    bool bmpOk = false;

    bool adsOk = false;

    bool loraOk = false;
    bool loraTested = false;

    bool sdOk = false;
    bool sdTested = false;

    bool wifiRunning = false;

    bool wifiClientConnected = false;

    uint8_t wifiClients = 0;
};
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

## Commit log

2026-07-29 Renomeia pasta Firmware para firmware
2026-08-11 Reverte main para o estado limpo do v2.1.0 (desfaz o merge publicado por engano -- LICENSE/README/PCB antigos continuam acessiveis pela tag v1.0)
